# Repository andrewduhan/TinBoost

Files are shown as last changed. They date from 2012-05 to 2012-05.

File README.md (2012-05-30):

TinBoost
========

A simple holder for an OKR-T/6 bucking variable voltage converter, designed to fit in an Altoids-sized tin alongside two 18650 Lithium Ion batteries

Board layout

Output adjustable from ~3.5V - 6V as is.   You can go as low as 1V output if you change the values of the 220 resistors.

The barrel jack is connected directly to battery + and -.  It is intended to allow easy in-circuit charging using an external Lithium-Ion charger appropriate for the battery (7.2V in the case of dual Li-Ion).  It could also be used as an unregulated output direct from the battery.  

**DO NOT CONNECT A STANDARD DC POWER SUPPLY TO THE DC JACK, YOU WILL DAMAGE YOUR BATTERY AND PROBABLY START A FIRE**

## BOM:
* OKR-T/6 (manually spread the pins to fit the board holes)
* C&K 1101 6A Switch (digikey # CKN5001)
* E-Switch illuminated right-angle tactile switch (digikey # EG4685-5)
* Bourns 3310Y 1k Pot (digikey # 3310Y-001-102L)
* 2x small through-hole tantalum 10uf caps
* 2x small 220ohm throughhole resistors ( for trim adjust )
* 1x small 6.8k throughhole resistor ( for EN pulldown )
* 1x small 1kohm throughhole resostor ( for tac switch LED )
* 1x standard through-hole DC barrel jack

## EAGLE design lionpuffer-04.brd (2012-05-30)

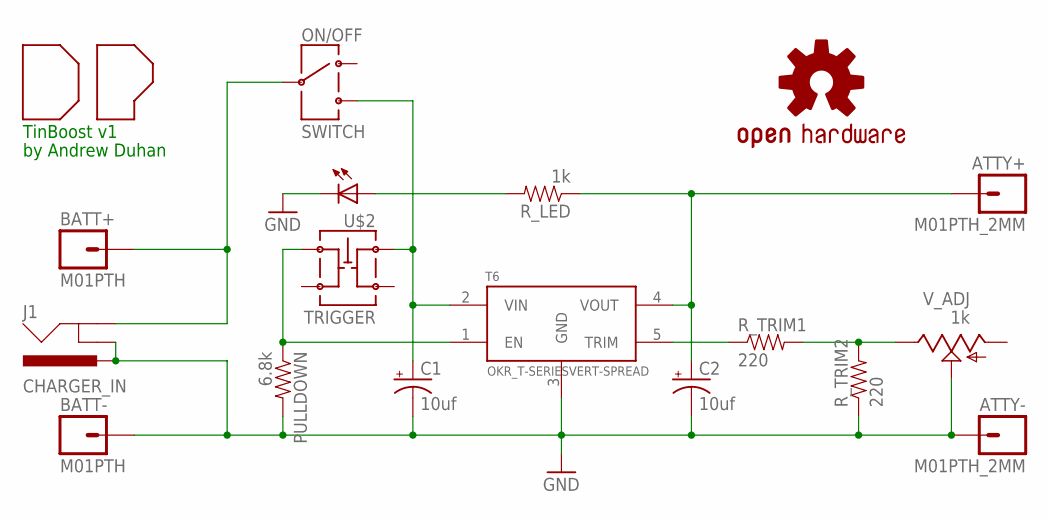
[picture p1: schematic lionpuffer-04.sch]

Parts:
ATTY+: M01PTH_2MM; 1X01_2MM
ATTY-: M01PTH_2MM; 1X01_2MM
BATT+: M01PTH; 1X01
BATT-: M01PTH; 1X01
C1, C2: 10uf; CPOL-RADIAL-10UF-25V
J1: CHARGER_IN; POWER_JACK_PTH
ON/OFF: SWITCH; SWITCH-CK1101
PULLDOWN: 6.8k; 1/6W-RES
R_LED: 1k; 1/6W-RES
R_TRIM1, R_TRIM2: 220; 1/6W-RES
T6: OKR_T-SERIESVERT-SPREAD; OKR-T/6_10-VERT-SPACED
U$1: OSHW-LOGOM; OSHW-LOGO-M
U$2: TRIGGER; E-SWITCH_TL1250
U$3: DP_LOGO
V_ADJ: 1k; POT-TOP-BOURNS

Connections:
ATTY+: ATTY+.1, C2.1 (+), R_LED.1, T6.4 (VOUT)
BATT+: BATT+.1, J1.GND, ON/OFF.2
GND: ATTY-.1, BATT-.1, C1.2 (-), C2.2 (-), J1.GNDBREAK, J1.PWR, PULLDOWN.2, R_TRIM2.1, T6.3 (GND), U$2.5 (C), V_ADJ.2 (W)
unnamed: R_TRIM1.2, R_TRIM2.2, V_ADJ.3 (B)
unnamed: PULLDOWN.1, T6.1 (EN), U$2.3
unnamed: R_TRIM1.1, T6.5 (TRIM)
unnamed: R_LED.2, U$2.6 (A)
VIN: C1.1 (+), ON/OFF.3, T6.2 (VIN), U$2.1

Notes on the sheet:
TinBoost v1
by Andrew Duhan

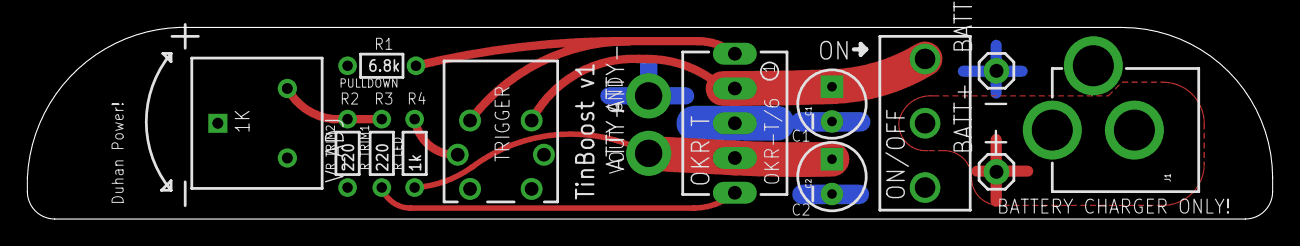
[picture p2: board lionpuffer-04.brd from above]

Board: 2 copper layers, 91.0 x 14.0 mm, 17 parts (1 on the bottom side), 8 nets.

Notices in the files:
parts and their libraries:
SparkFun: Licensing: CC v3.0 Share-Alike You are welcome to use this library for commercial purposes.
